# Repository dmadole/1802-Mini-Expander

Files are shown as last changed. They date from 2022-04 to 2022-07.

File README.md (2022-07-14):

# 1802-Mini-Expander-RTC
This is the memory and port expander plus real-time clock card for the [1802/Mini](https://github.com/dmadole/1802-Mini) system. It supports the following features:

### Memory Expansion

* 32K added ROM or RAM
* Can be addressed in either upper or lower 32K block
* Can be split on any power of 2 size from the top or bottom of the block
* Splitting the block allows mixed ROM and RAM in the same 32K block
* Expansion memory can be enabled or disabled under software control
* Can be set to be enabled or disabled be default at system reset

The software control can be used to implement bank switching, such a 32K ROM that includes diagnostics run at boot time but is then replaced with RAM except for the last 2K or 4K which has BIOS. Or you could have a system that can start either a Riley “Disk-less ROM” with 32K RAM/32K ROM, or a Elf/OS system with 60K RAM/2K ROM under control of a software menu.

### Real Time Clock

* Keeps month, day, year, hour, minute, second time and date
* Corrects for leap years
* Can provide a periodic interrupt at 64 Hz or once per second, minute, or hour
* Can also provide a pollable signal on an EF line at the same rates
* Uses a replaceable BR1225 coin cell battery
* 1.3uA standby current gives approximately 5 years battery life
* Uses one I/O port 1-7 which is two-level group addressable

I have written a loadable driver that presents the “standard” interface to Elf/OS 4 to enable date and time, and there is also a new BIOS that supports all features of this card available here:

> https://github.com/dmadole/1802-Mini/tree/master/firmware

### Port Expander

* Implements low 4 bits of the Microboard group scheme
* Written group select value can be read back also
* Implements a “group 0” which is automatically selected at reset
* Total of 5 groups gives 35 maximum I/O ports (5 groups of 7)
* Allows for high 4 bits to be implemented on another card
* Uses one I/O port 1-7

Gerber files for the PCBs and PDF schematics can be found in [Releases](https://github.com/dmadole/1802-Mini-Expander-RTC/releases).

BOMS and any applicable errata or other notes can be found in [notes](https://github.com/dmadole/1802-Mini-Expander-RTC/tree/main/notes).

For availability of kits and bare PCBs please see http://madole.net/1802/mini/kits

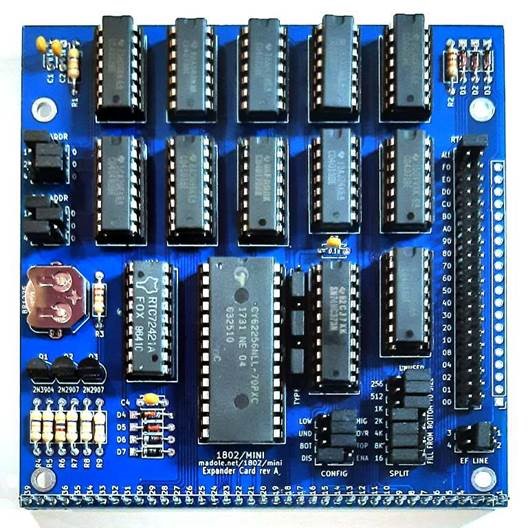
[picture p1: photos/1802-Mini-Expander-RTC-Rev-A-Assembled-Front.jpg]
1802/Mini Expander RTC Front


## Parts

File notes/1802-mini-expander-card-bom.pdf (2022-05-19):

### EXPANSION CARD

Qty | Description | Location | Manufacturer Manufacturer # | Vendor | Vendor #

Integrated Circuits
1 | 62256 type 32Kx8 Static RAM | U12 | Cypress | CY62256NL-70PC | Digikey | 2156-CY62256NL-70PC-ND
1 | CD4001 | U5 | TI | CD4001BE | Digikey | 296-2028-ND
1 | CD4002 | U1 | TI | CD4002BE | Digikey | 296-2029-5-ND
1 | CD4013 | U9 | TI | CD4013BE | Digikey | 296-2033-5-ND
2 | CD4023 | U3-4 | TI | CD4023BE | Digikey | 296-2041-ND
1 | CD4048 | U14 | TI | CD4048BE | Digikey | 296-2054-5-ND
1 | CD4049 | U6 | TI | CD4049UBE | Digikey | 296-2055-5-ND
1 | CD4071 | U10 | TI | CD4071BE | Digikey | 296-2062-ND
1 | CD4073 | U2 | TI | CD4073BE | Digikey | 296-2064-ND
1 | CD4503 | U7 | TI | CD4503BE | Digikey | 296-2071-5-ND
1 | CD40175 (or 74C175 or 74HC175) | U8 | TI | CD40175BE | Digikey | 296-14251-5-ND
1 | CD40373 (or 74C373 ot 74HC373) | U13 | TI | SN74HC373N | Digikey | 296-1591-5-ND
1 | RTC-72421 | U11 | Epson | RTC-72421A | Nexxon | RTC72421A

Discrete Components
1 | Resistor 1/4 watt 4.7K | R6 | Stackpole | CF14JT4K70 | Digikey | CF14JT4K70CT-ND
2 | Resistor 1/4 watt 22K | R2-3 | Stackpole | CF14JT470K | Digikey | CF14JT470KCT-ND
6 | Resistor 1/4 watt 47K | R1,4-5,7-9 | Stackpole | CF14JT47K0 | Digikey | CF14JT47K0CT-ND
5 | Switching Diode 1N4148 | D1-5 | ON Semi | 1N4148 | Digikey | 1N4148FS-ND
2 | Zener Diode 3.9v 1N4622 | D6-7 | Microchip | 1N4148 | Digikey | 1N4622-1-ND
4 | Ceramic capacitor 0.1uF radial 0.2" | C1-4 | Vishay | K104K10X7RF5UH5 | Digikey | BC2665CT-ND
2 | 2N2907 Transistor TO-92 | Q2-3 | ON Semi | PN2907ABU | Digikey | PN2907ABUFS-ND
1 | 2N3904 Transistor TO-92 | Q1 | ON Semi | 2N3904TFR | Digikey | 2N3904D26ZCT-ND
1 | BR1225 coin cell 3v | | Panasonic | BR1225 | Digikey | P183-ND

Interconnect and Mechanical
1 | Socket 20 pin 0.1" long tail | | Samtec | SSQ-120-03-T-S | Digikey | SAM1206-20-ND
1 | Straight dual row header 21 position | | Sullins | PREC021DAAN-RC | Digikey | S2012EC-21-ND
19 | Straight header 3 pins 0.1" | | Sullins | PREC003SAAN-RC | Digikey | S1012EC-03-ND
1 | Straight header 9 pins 0.1" | | Sullins | PREC009SAAN-RC | Digikey | S1012EC-09-ND
22 | Jumper shunts 0.1" | | Sullins | STC02SYAN | Digikey | S9000-ND
1 | Coin cell retainer 12mm | | Keystone | 3001 | Digikey | 36-3001-ND
4 | 0.5 inch standoff spacer | | RAF | 4505-440-AL-7 | Jameco | 393474

Integrated Circuit Sockets
1 | DIP socket 28 pin 0.6" | U12 | On Shore | ED28DT | Digikey | ED3052-5-ND
1 | DIP socket 20 pin 0.3" | U13 | On Shore | ED20DT | Digikey | ED3054-5-ND
1 | DIP socket 18 pin 0.3" | U11 | On Shore | ED18DT | Digikey | ED3047-5-ND
4 | DIP socket 16 pin 0.3" | U6-8,14 | On Shore | ED16DT | Digikey | ED3046-5-ND
7 | DIP socket 14 pin 0.3" | U1-5,9-10 | On Shore | ED14DT | Digikey | ED3045-5-ND

Circuit Board and Expansion
1 | Circuit Board | | Madole | | JLCPCB
1 | Socket 39 pin 0.1" long tail | | Samtec | SSQ-139-03-T-S | Digikey | SAM1206-39-ND

Note: Part numbers, manufacturers, and vendors are typical of what is supplied. Substitutions may be made based on availability at time of ordering.

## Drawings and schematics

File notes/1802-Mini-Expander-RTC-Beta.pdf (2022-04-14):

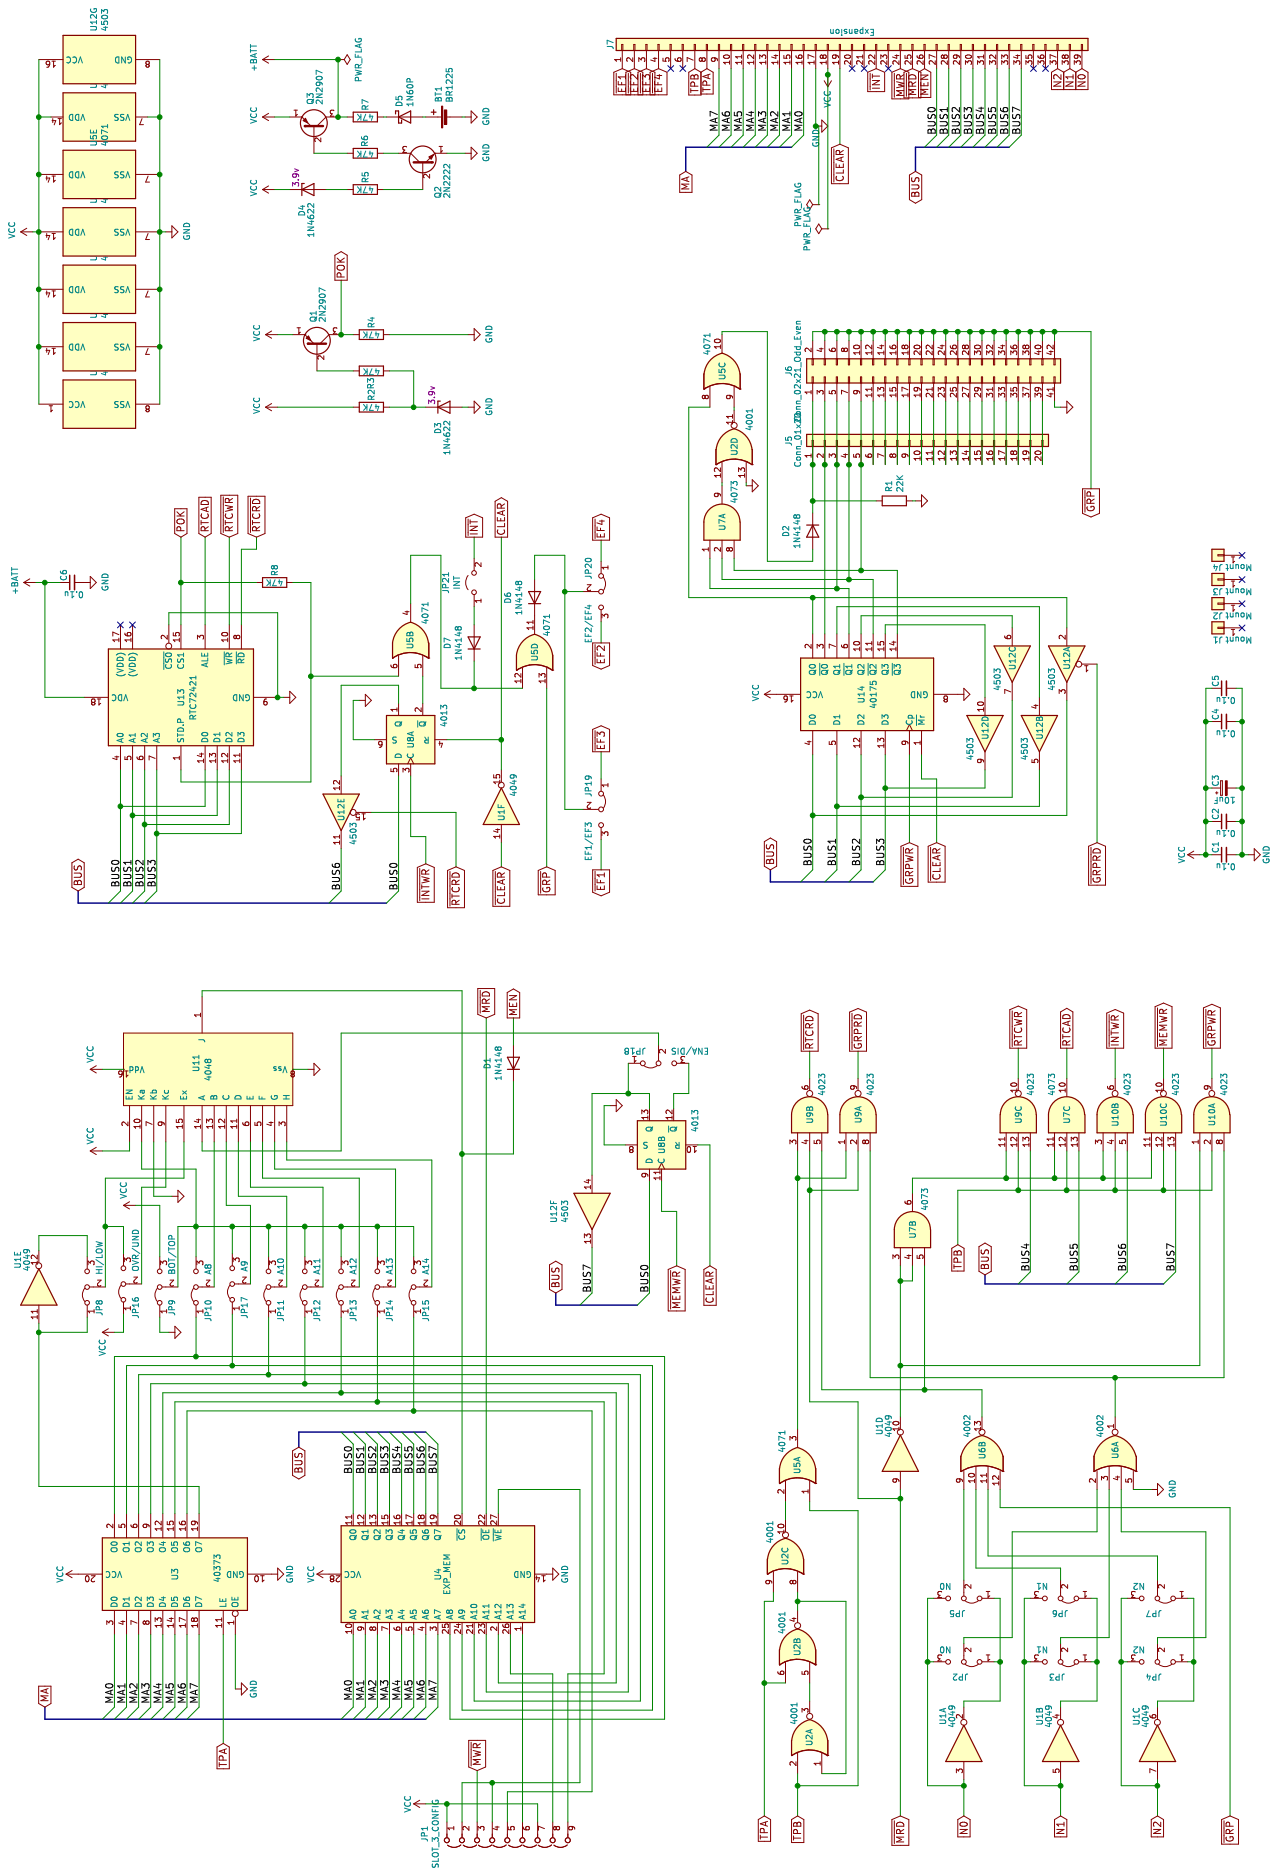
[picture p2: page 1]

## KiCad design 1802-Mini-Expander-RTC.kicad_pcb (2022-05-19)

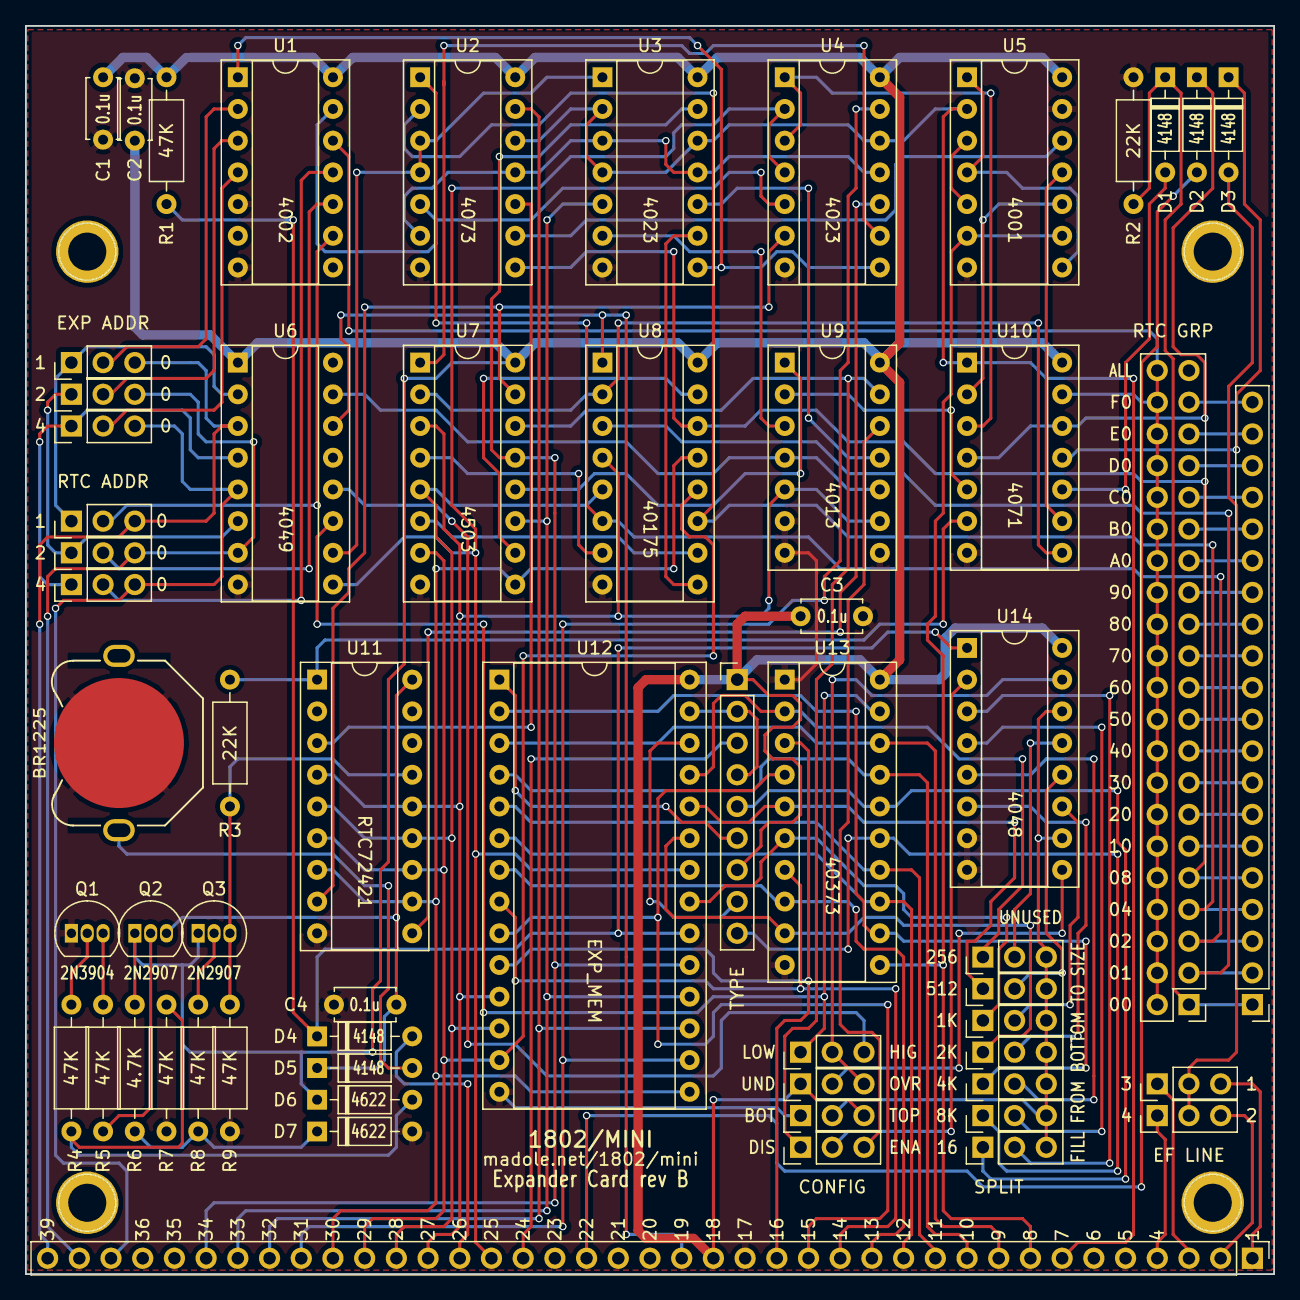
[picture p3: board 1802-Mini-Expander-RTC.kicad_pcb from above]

Board: 2 copper layers, 100.0 x 100.0 mm, 65 parts (0 on the bottom side), 126 nets.

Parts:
BT1: BR1225; Keystone 3001
C1, C2, C3, C4: 0.1u; C_Disc_D4.7mm_W2.5mm_P5.00mm
D1, D2, D3, D4, D5: 1N4148; D_DO-35_SOD27_P7.62mm_Horizontal
D6, D7: 1N4622; D_DO-35_SOD27_P7.62mm_Horizontal
J1, J2, J3, J4: Mount; 1pin
J5: Conn_01x20; PinHeader_1x20_P2.54mm_Vertical
J6: Conn_02x21_Odd_Even; PinHeader_2x21_P2.54mm_Vertical
J7: Expansion; Pin_Header_Straight_1x39_Pitch2.54mm
JP1: SLOT_3_CONFIG; PinHeader_1x09_P2.54mm_Vertical
JP2, JP5: N0; PinHeader_1x03_P2.54mm_Vertical
JP3, JP6: N1; PinHeader_1x03_P2.54mm_Vertical
JP4, JP7: N2; PinHeader_1x03_P2.54mm_Vertical
JP8: HI/LOW; PinHeader_1x03_P2.54mm_Vertical
JP9: BOT/TOP; PinHeader_1x03_P2.54mm_Vertical
JP10: A8; PinHeader_1x03_P2.54mm_Vertical
JP11: A10; PinHeader_1x03_P2.54mm_Vertical
JP12: A11; PinHeader_1x03_P2.54mm_Vertical
JP13: A12; PinHeader_1x03_P2.54mm_Vertical
JP14: A13; PinHeader_1x03_P2.54mm_Vertical
JP15: A14; PinHeader_1x03_P2.54mm_Vertical
JP16: OVR/UND; PinHeader_1x03_P2.54mm_Vertical
JP17: A9; PinHeader_1x03_P2.54mm_Vertical
JP18: ENA/DIS; PinHeader_1x03_P2.54mm_Vertical
JP19: EF1/EF3; PinHeader_1x03_P2.54mm_Vertical
JP20: EF2/EF4; PinHeader_1x03_P2.54mm_Vertical
Q1: 2N3904; TO-92_Inline
Q2, Q3: 2N2907; TO-92_Inline
R1, R4, R5, R7, R8, R9: 47K; R_Axial_DIN0207_L6.3mm_D2.5mm_P10.16mm_Horizontal
R2, R3: 22K; R_Axial_DIN0207_L6.3mm_D2.5mm_P10.16mm_Horizontal
R6: 4.7K; R_Axial_DIN0207_L6.3mm_D2.5mm_P10.16mm_Horizontal
U1: 4002; DIP-14_W7.62mm_Socket
U2: 4073; DIP-14_W7.62mm_Socket
U3, U4: 4023; DIP-14_W7.62mm_Socket
U5: 4001; DIP-14_W7.62mm_Socket
U6: 4049; DIP-16_W7.62mm_Socket
U7: 4503; DIP-16_W7.62mm_Socket
U8: 40175; DIP-16_W7.62mm_Socket
U9: 4013; DIP-14_W7.62mm_Socket
U10: 4071; DIP-14_W7.62mm_Socket
U11: RTC72421; DIP-18_W7.62mm_Socket
U12: EXP_MEM; DIP-28_W15.24mm_Socket
U13: 40373; DIP-20_W7.62mm_Socket
U14: 4048; DIP-16_W7.62mm_Socket

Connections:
+BATT: C4.1, D5.1, Q2.3, U11.18
/BUS0: J7.27, U7.3, U8.4, U9.5, U9.9, U11.4, U11.14, U12.11
/BUS1: J7.28, U7.5, U8.5, U11.5, U11.13, U12.12
/BUS2: J7.29, U7.7, U8.12, U11.6, U11.12, U12.13
/BUS3: J7.30, U7.9, U8.13, U11.7, U11.11, U12.15
/BUS4: J7.31, U4.13, U12.16
/BUS5: J7.32, U2.13, U12.17
/BUS6: J7.33, U3.5, U7.11, U12.18
/BUS7: J7.34, U3.13, U7.13, U12.19
/MA0: J7.16, U12.10, U13.3
/MA1: J7.15, U12.9, U13.4
/MA2: J7.14, U12.8, U13.7
/MA3: J7.13, U12.7, U13.8
/MA4: J7.12, U12.6, U13.13
/MA5: J7.11, U12.5, U13.14
/MA6: J7.10, U12.4, U13.17
/MA7: J7.9, U12.3, U13.18
CLEAR: U6.15, U9.4, U9.10
GND: BT1.2, C1.2, C2.2, C3.2, C4.2, D7.2, J6.41, J7.17, JP9.1, Q1.1, R2.2, R7.2, R9.2, U1.5, U1.7, U2.7, U3.7, U4.7, U5.7, U5.13, U6.8, U7.8, U8.8, U9.6, U9.7, U9.8, U10.7, U11.2, U11.9, U12.14, U13.1, U13.10, U14.7, U14.8
MEN: D4.2, J7.26
N0: J7.39, JP2.3, JP5.3, U6.3
N1: J7.38, JP3.3, JP6.3, U6.7
N2: J7.37, JP4.3, JP7.3, U6.5
unnamed: BT1.1, D5.2
unnamed: D1.1, J5.1, J6.1, R2.1
unnamed: D1.2, U10.10
unnamed: D2.1, U10.4, U10.12
unnamed: D3.1, U10.11
unnamed: D3.2, JP19.2, JP20.2
unnamed: D4.1, R1.2, U12.20, U14.1
unnamed: D6.2, R4.1, R7.1
unnamed: D7.1, R6.2, R8.1
unnamed: J5.2, J6.3, U8.3
unnamed: J5.3, J6.5, U2.1, U8.6
unnamed: J5.4, J6.7, U2.2, U8.11
unnamed: J5.5, J6.9, U2.8, U8.14
unnamed: J5.6, J6.11
unnamed: J5.7, J6.13
unnamed: J5.8, J6.15
unnamed: J5.9, J6.17
unnamed: J5.10, J6.19
unnamed: J5.11, J6.21
unnamed: J5.12, J6.23
unnamed: J5.13, J6.25
unnamed: J5.14, J6.27
unnamed: J5.15, J6.29
unnamed: J5.16, J6.31
unnamed: J5.17, J6.33
unnamed: J5.18, J6.35
unnamed: J5.19, J6.37
unnamed: J5.20, J6.39
unnamed: JP1.2, JP1.4, U12.27
unnamed: JP1.5, JP15.1, U13.16
unnamed: JP1.6, U12.1
unnamed: JP1.8, U12.26
unnamed: JP1.9, JP14.1, U13.15
unnamed: JP2.1, JP5.1, U6.2
unnamed: JP2.2, U1.2
unnamed: JP3.1, JP6.1, U6.6
unnamed: JP3.2, U1.3
unnamed: JP4.1, JP7.1, U6.4
unnamed: JP4.2, U1.4
unnamed: JP5.2, U1.9
unnamed: JP6.2, U1.10
unnamed: JP7.2, U1.11
unnamed: JP8.1, U6.11, U13.19
unnamed: JP8.3, U6.12
unnamed: JP10.1, U12.25, U13.2
unnamed: JP10.2, U14.13
unnamed: JP9.2, JP10.3, JP11.3, JP12.3, JP13.3, JP14.3, JP15.3, JP17.3, U14.10, U14.14
unnamed: JP11.1, U12.21, U13.6
unnamed: JP11.2, U14.11
unnamed: JP12.1, U12.23, U13.9
unnamed: JP12.2, U14.6
unnamed: JP13.1, U12.2, U13.12
unnamed: JP13.2, U14.5
unnamed: JP14.2, U14.4
unnamed: JP15.2, U14.3
unnamed: JP16.2, U14.9
unnamed: JP8.2, JP16.3, U14.15
unnamed: JP17.1, U12.24, U13.5
unnamed: JP17.2, U14.12
unnamed: JP18.1, U7.14, U9.13
unnamed: JP18.2, U14.2
unnamed: JP18.3, U9.12
unnamed: Q1.2, R4.2
unnamed: Q1.3, R5.1
unnamed: Q2.2, R5.2
unnamed: Q3.2, R8.2
unnamed: R3.2, U10.6, U11.1
unnamed: U1.1, U3.8, U4.8
unnamed: U1.13, U2.5, U4.5
unnamed: U2.3, U2.4, U3.1, U6.10
unnamed: U2.9, U5.12
unnamed: U2.6, U2.11, U3.3, U3.11, U4.11
unnamed: U5.1, U5.4, U5.8
unnamed: U5.3, U5.5
unnamed: U7.4, U8.7
unnamed: U7.6, U8.10
unnamed: U7.10, U8.15
unnamed: U7.12, U9.1
unnamed: U5.10, U10.2
unnamed: U4.1, U4.3, U10.3
unnamed: U9.2, U10.5
unnamed: U7.2, U8.2, U10.8
unnamed: U5.11, U10.9
POK: Q3.3, R3.1, R9.1, U11.15
RTCAD: U2.10, U11.3
TPA: J7.8, U5.6, U5.9, U13.11
TPB: J7.7, U2.12, U3.2, U3.4, U3.12, U4.12, U5.2, U10.1
VCC: C1.1, C2.1, C3.1, D6.1, J7.18, JP1.1, JP1.7, JP9.3, JP16.1, Q2.1, Q3.1, R1.1, R6.1, U1.14, U2.14, U3.14, U4.14, U5.14, U6.1, U7.16, U8.16, U9.14, U10.14, U12.28, U13.20, U14.16
~CLEAR: J7.19, U6.14, U8.1
~EF1: J7.1, JP19.3
~EF2: J7.2, JP20.3
~EF3: J7.3, JP19.1
~EF4: J7.4, JP20.1
~GRP: J6.2, J6.4, J6.6, J6.8, J6.10, J6.12, J6.14, J6.16, J6.18, J6.20, J6.22, J6.24, J6.26, J6.28, J6.30, J6.32, J6.34, J6.36, J6.38, J6.40, J6.42, U1.12, U10.13
~GRPRD: U4.9, U7.1
~GRPWR: U3.9, U8.9
~INT: D2.2, J7.22
~INTWR: U3.6, U9.3
~MEMWR: U3.10, U9.11
~MRD: J7.25, U4.2, U4.4, U6.9, U12.22
~MWR: J7.24, JP1.3
~RTCRD: U4.6, U7.15, U11.8
~RTCWR: U4.10, U11.10

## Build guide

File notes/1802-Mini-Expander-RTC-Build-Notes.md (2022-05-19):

# 1802/Mini Expander RTC Card Notes

Follow usual assembly practices, which I will not document here. I recommend installing the lowest-height components first (resistors, diodes, right-angle connectors), then the next higher (sockets), and so on.

Please review all jumper settings before trying to operate the board. In particular, a group select jumper must be installed for the board to work, in systems without group I/O capability, this should be on the ALL position.

## Diodes

Note that there are two different types of diodes on this board, 1N4148 switching diodes and 1N4622 zener diodes. Please be sure to install the correct diodes in the correct locations. The 1N4148 diodes are typically clear glass with orange internal contacts and install at D1-5, and the 1N4622 diodes are opaque black or gray and install at D6-7.

## Port Expander Configuration

The port expander uses a single I/O port which is set by the `EXP ADDR` jumpers by selecting the appropriately labeled address values. Valid values are 1-7, do not set all jumpers to 0.

The port expander implements the low four bits of this port and maps them to the `01`, `02`, `04`, and `08` expander bus pins as active-low. When none of the bits are set the `00` pin on the expander bus will be active; the register will be cleared to 00 when the system is reset.

## Real Time Clock Configuration

The RTC uses a single I/O port which is set by the `RTC ADDR` jumpers by selecting the appropriately labeled address values. Valid values are 1-7, do not set all jumpers to 0.

The RTC can be used with two-level I/O by installing a jumper appropriately on the `I/O GROUP` jumpers. For the port to always be present at its assigned address regardless of the port exapander register, set to `ALL`. To be present in the default group which will be selected at reset, set to `00`. Otherwise, jumper to the appropriate grounp.

## Memory Configuration

The expansion card adds 32K of RAM or EEPROM that can be mapped to either the upper or lower 32K, and can be split within the block so that either the upper or lower part of the block comes from the expansion card, and the other part comes from the on-processor memory. In memory maps with high ROM it is recommended that the ROM is on the processor card, as only that sock has the ability to temporarily map the ROM to 0000 at reset to allow automatic booting, and that RAM is used on the expansion card.

### Memory Type

The memory type is configured with jumpers on a 9-pin jumper block immediately adjacent to the memory socket as follows:

| Type | Jumpers |
|:---:|:---:|
| 32K RAM (62256) | 2/3, 5/6, 8/9 |

### Memory Size

The `SPLIT` jumpers determine the split point in the memory block between the on-processor memory and the expansion memory and can split the block at 256, 512, 1K, 2K, 4K, 8K, or 16K bytes, or the block can be not split at all. This allows, for example, to have part ROM and part RAM within the same memory bank.

To set the split size, install jumpers to the left starting at the labeled split point and for all higher split points. The jumpers for lower split points should be to the right side. For example, for a 2K split, set jumpers to the left for the `2K`, `4K`, `8K`, and `16K` positions, and to the right for the `256`, `512`, and `1K` positions.

To not split at all and have a single 32K block, set all positions to the right.

### Memory Configuration

The `CONFIG` jumpers determine where in the memory map the expansion memory resides.

The `LOW/HIG` jumper selects whether the expansion memory is in the 0000-7FFFF block (jumper to `LOW`) or the 8000-FFFF block (jumper to `HIG`).

The `TOP/BOT` jumper selected whether the split point is measured from the top (jumper to `TOP`) or the bottom (jumper to `BOT`) of the memory block. 

The `UND/OVR` jumper selects whether the expansion memory is "under" or "over" the split point. Jumpering to `UND` means the expansion memory will be at the beginning or end (depending on the `TOP/BOT` jumper) of memory in the block, with the on-processor memory on the other side of the split. Jumpering to `OVR` reverses this.

The `ENA/DIS` jumper determines whether the expansion memory will be enabled (jumper to `ENA`) or disabled (jumper to `DIS`) at reset. When disabled, the on-processor memory will occupy all of the memory block.

The following diagrams, based upon the example of a 2K split size, may help to clarify:

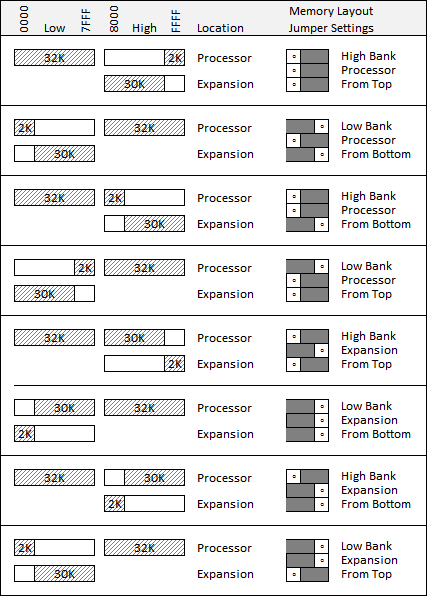
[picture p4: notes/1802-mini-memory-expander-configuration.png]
Jumper Settings
